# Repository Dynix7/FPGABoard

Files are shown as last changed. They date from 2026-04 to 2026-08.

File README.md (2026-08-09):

# FPGABoard
This is a FPGA (Field Programmable Array) board that consists of a iCE40 FPGA, FT2232 Programmer, and IO options. It has 2 PMOD headers (12 pin and 6 pin) along with an programming header and 26 pin header for anything else you want to plug in. On the board it has 3 LEDs and 3 buttons, allowing you to interact with the board without plugging anything in

# Why I Made It
I have a decent amount of experience working with microcontrollers but never any with FPGAs. I also want to learn Verilog which allows you to design circuits using programming, so a FPGA board would be perfect for this use case allowing me to experiment with Verilog and designing circuits while also learning something new.

# Pictures

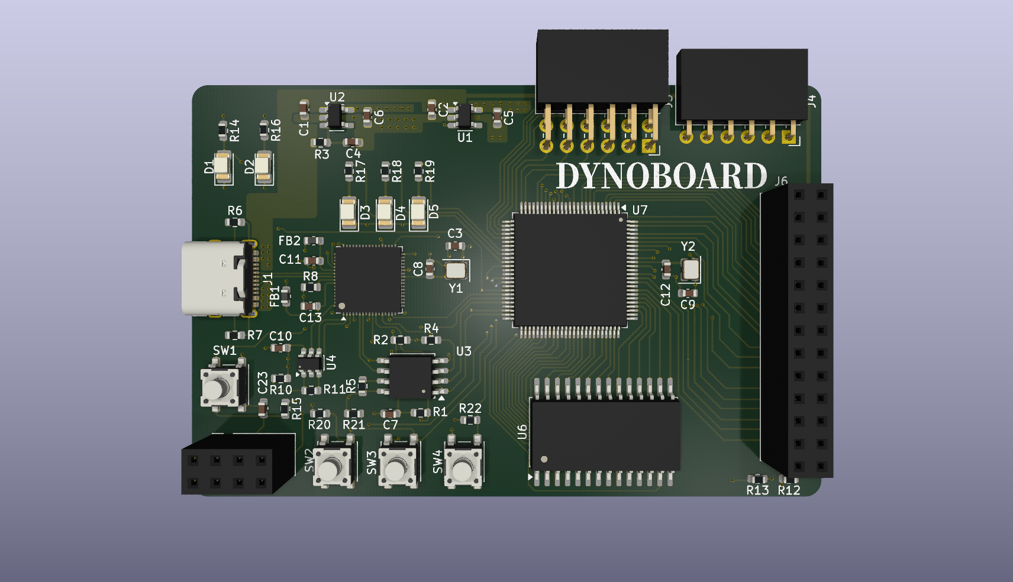
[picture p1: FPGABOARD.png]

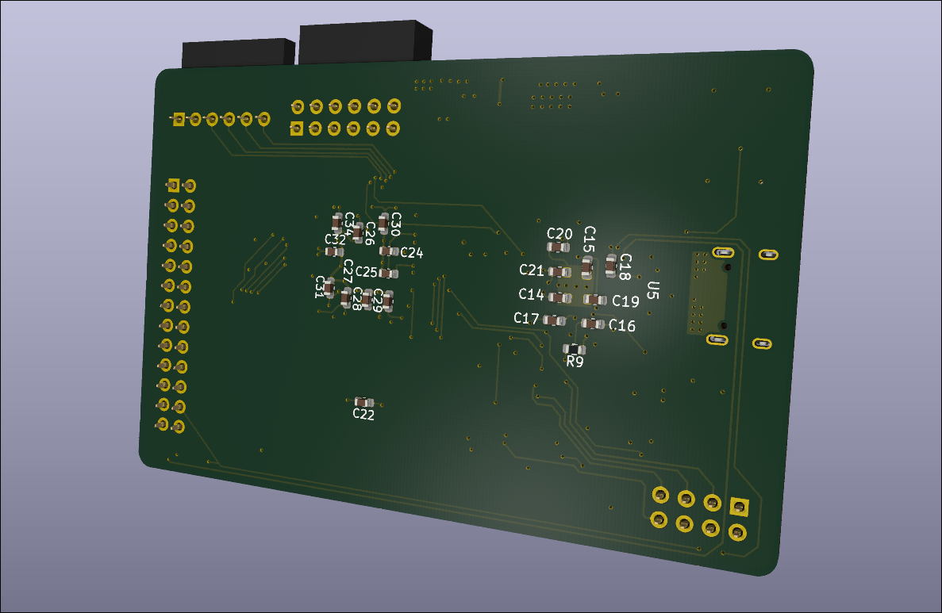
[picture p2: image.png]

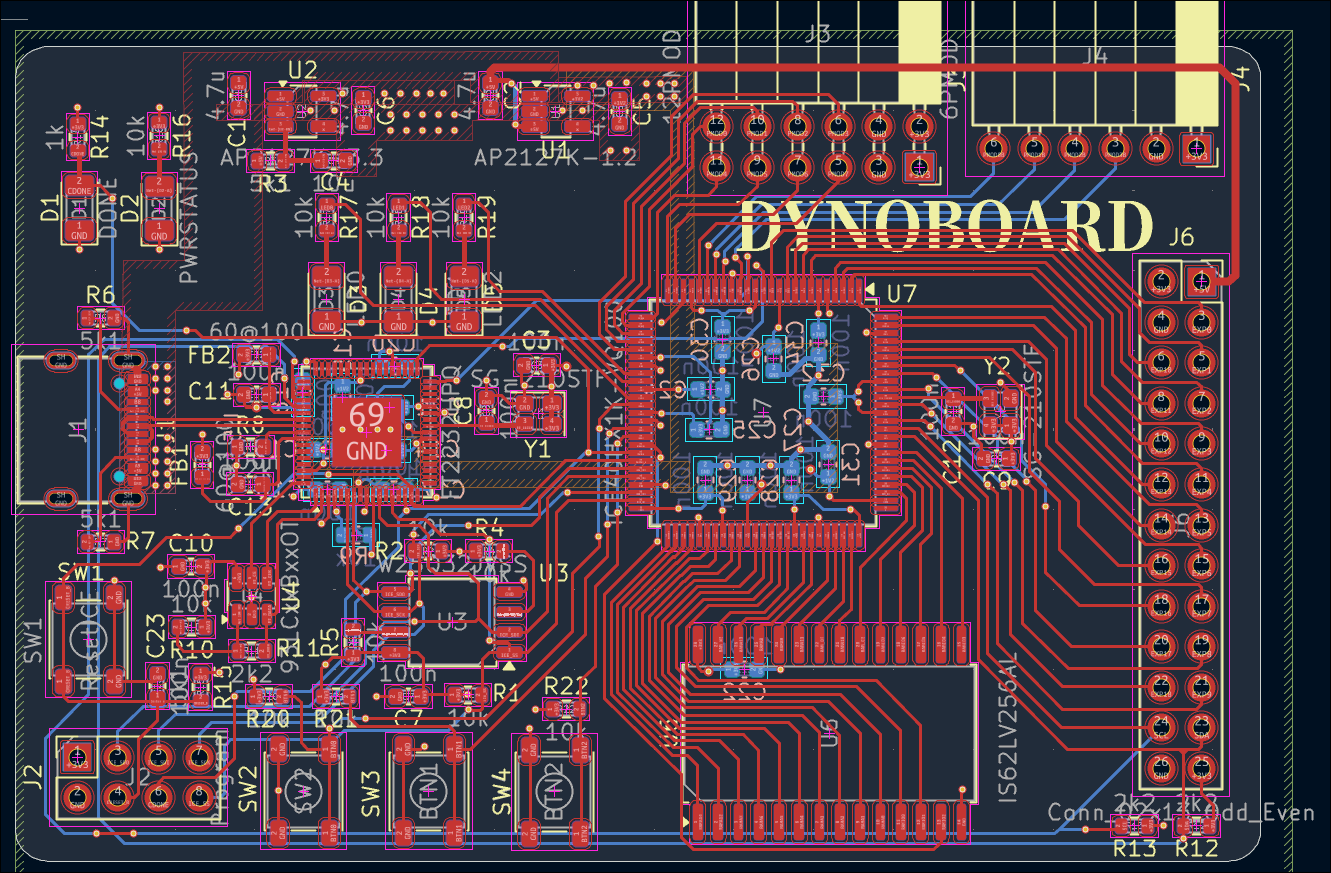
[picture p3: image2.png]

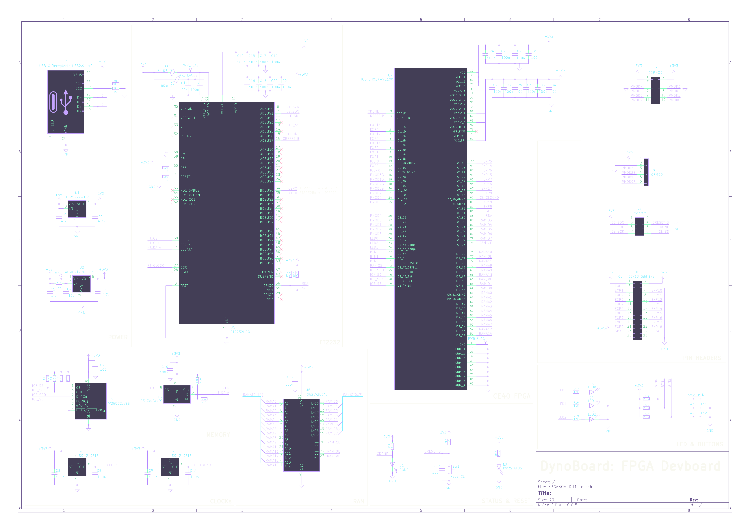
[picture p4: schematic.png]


# BOM

|Name |Purpose |Quantity|Total Cost (USD)|Link |Distributor|
|---|---|---|---|---|---|
|6 Pin Header |6 Pin PMOD Connector | |0.39 |https://www.lcsc.com/product-detail/C2935996.html |LCSC |
|2x6 Pin Header |12 Pin PMOD Connector | |0.74 |https://www.lcsc.com/product-detail/C47326634.html |LCSC |
|2x4 Pin Header |Programing Header | |0.52 |https://www.lcsc.com/product-detail/C7494793.html |LCSC |
|2x13 Pin Female Header|IO Pin Header | |0.32 |https://www.lcsc.com/product-detail/C19268725.html |LCSC |
|Ferrite Bead 60@100 |Power Filtering | |0.23 |https://www.lcsc.com/product-detail/C307775.html |LCSC |
|Solder Paste |Solder Components |1 |4.79 |https://www.aliexpress.us/item/3256809026940371.html |Aliexpress |
|4.7u Capacitors |Decoupling Capacitors | |0.10 | |LCSC |
|12k Resistor |Resistor | |0.11 | |LCSC |
|2.2k Resistor |Resistor | |0.13 | |LCSC |
|IS62LV256AL-45ULI |SRAM for Chip |1 |1.84 |https://www.digikey.com/short/70fz9v3d |Digikey |
|12Mhz Oscillator |Clock for FPGA and FT2232 |2 |0.87 |https://www.lcsc.com/product-detail/C37635404.html |LCSC |
|93LC66BT-I/OT |FT2232 Memory | |0.35 |https://www.digikey.com/short/q0nprmz5 |Digikey |
|AP2127K-1.2 |1.2V Voltage Regulator | |0.59 |https://www.lcsc.com/product-detail/C151376.html |LCSC |
|AP2127K-3.3 |3.3V Voltage Regulator | |0.53 |https://www.lcsc.com/product-detail/C156285.html |LCSC |
|FT2232HPQ |USB to SPI Chip for programming|1 |8.88 |https://www.lcsc.com/product-detail/C3228692.html |LCSC |
|iCE40HX1K-VQ100 |Main FPGA Chip |1 |12.17 |https://www.lcsc.com/product-detail/C1519043.html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|LCSC |
|Stencil |For PCB assembly |1 |7.11 | |JLCPCB |
|PCB |PCB for Build |5 |12.00 | |JLCPCB |

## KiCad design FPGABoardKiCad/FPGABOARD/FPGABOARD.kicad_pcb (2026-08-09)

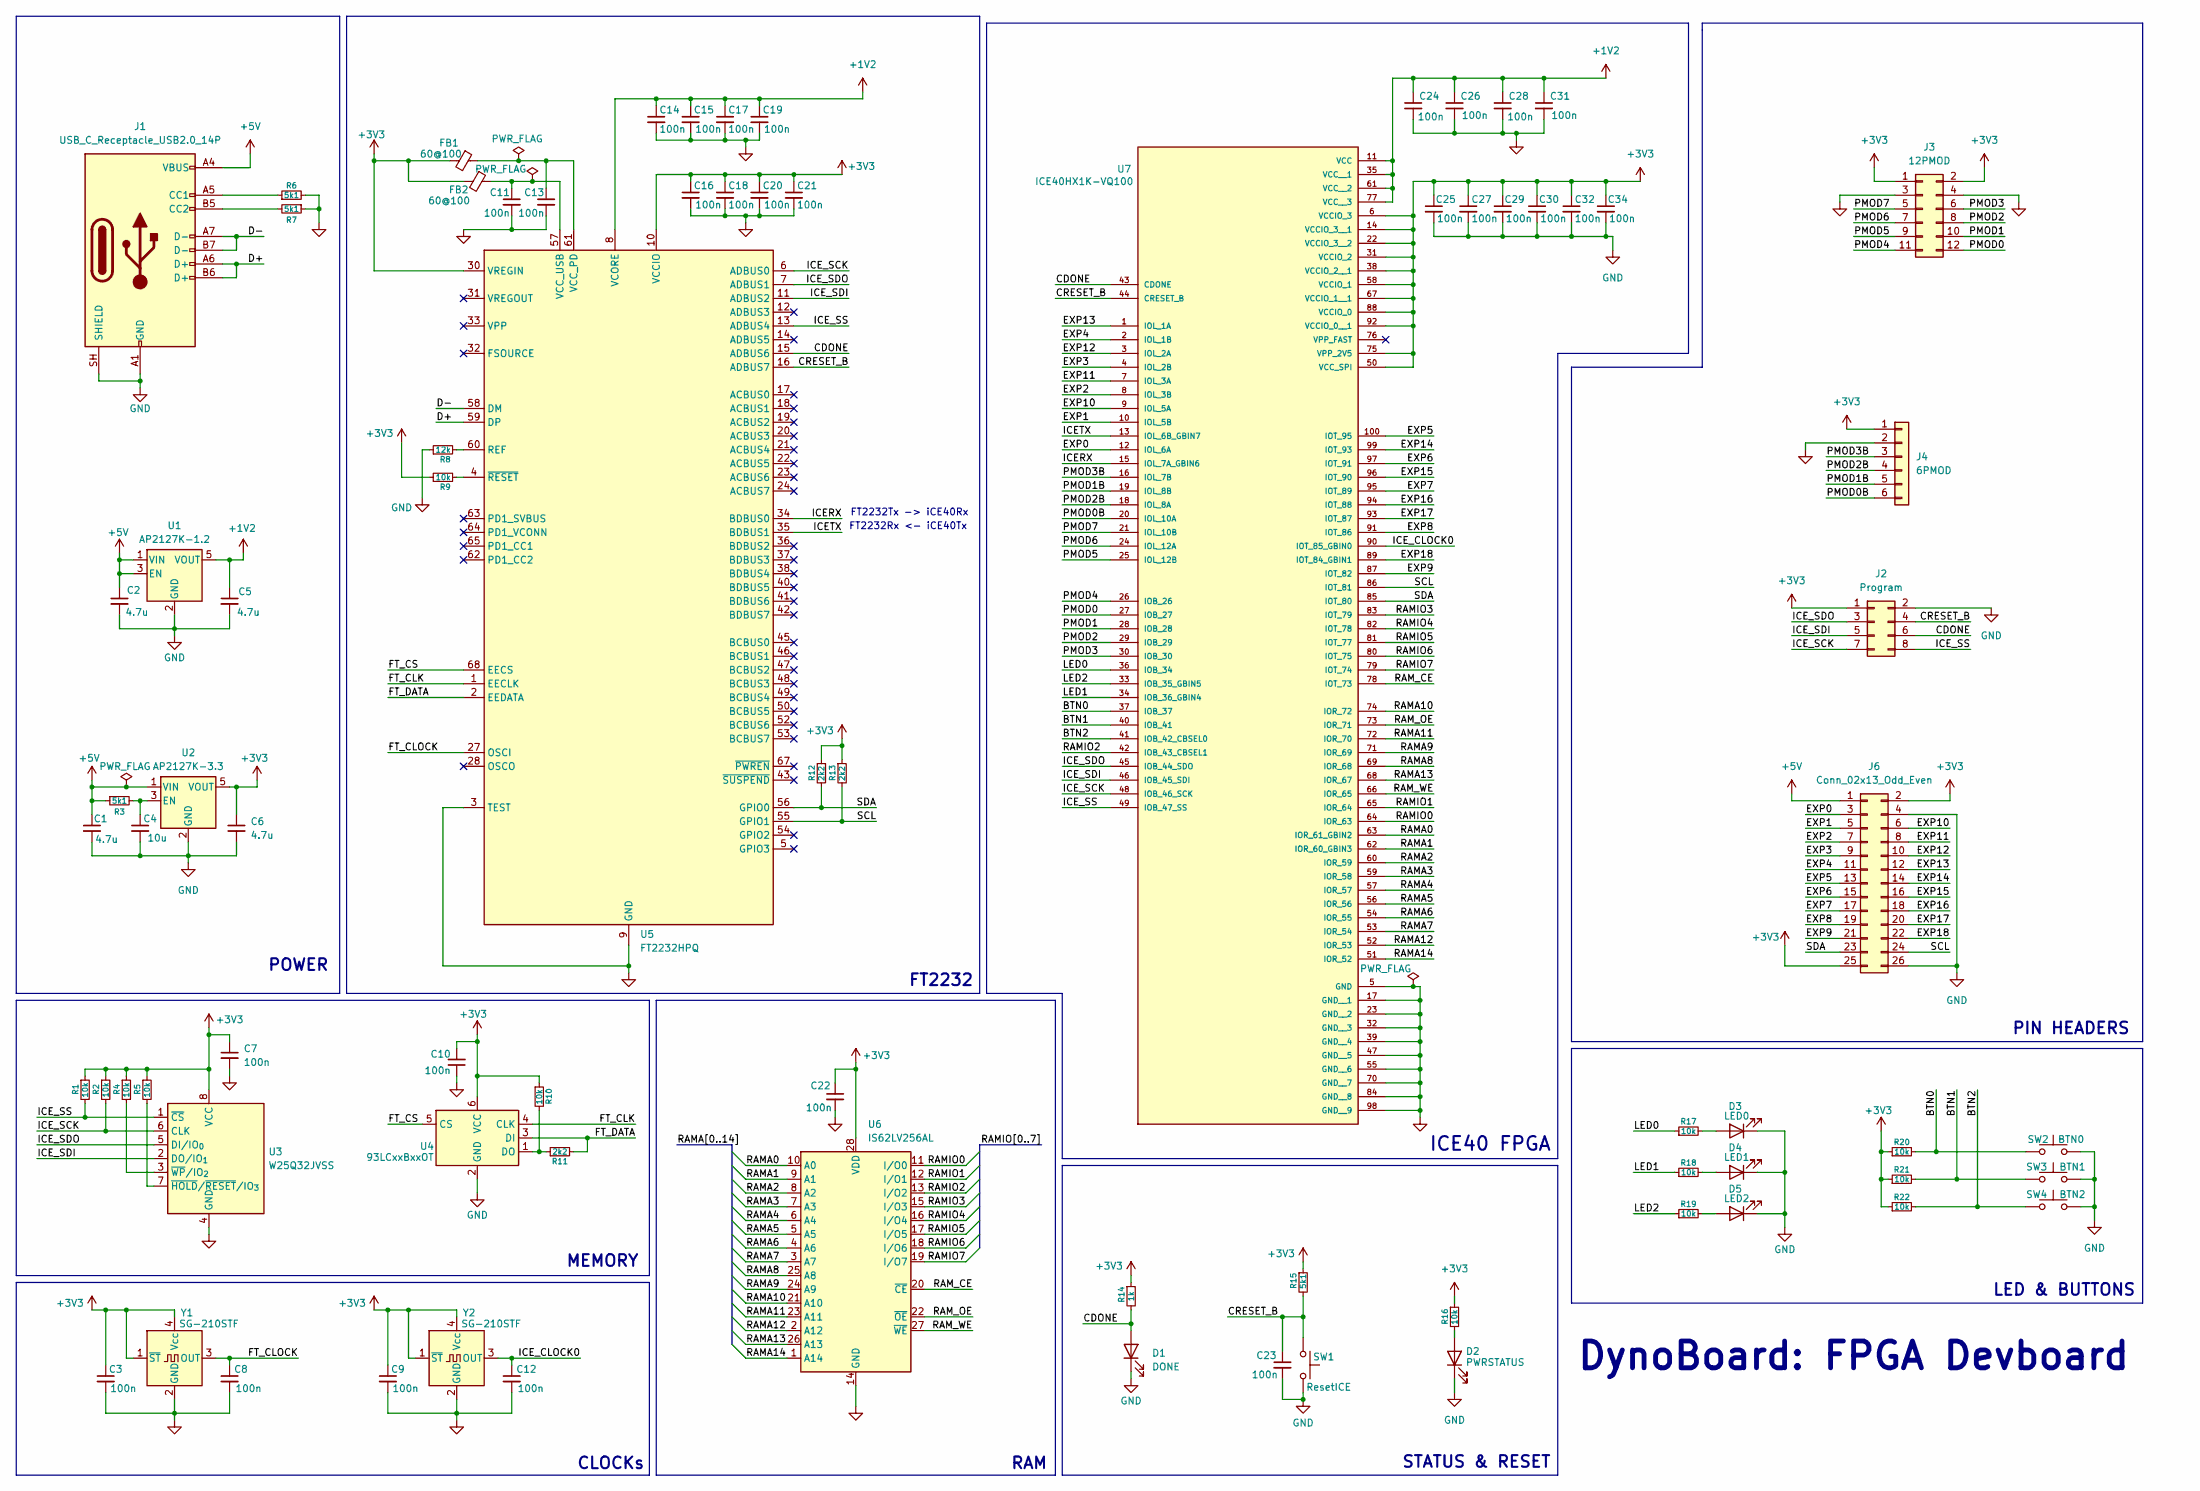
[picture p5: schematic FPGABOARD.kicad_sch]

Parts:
C1, C2, C5, C6: 4.7u; C_0603_1608Metric
C3, C7, C8, C9, C10, C11, C12, C13, C23: 100n; C_0603_1608Metric
C4: 10u; C_0603_1608Metric
C14, C15, C16, C17, C18, C19, C20, C21, C22, C24, C25, C26, C27, C28, C29, C30, C31, C32, C34: 100n; C_0603_1608Metric_Pad1.08x0.95mm_HandSolder
D1: DONE; LED_1206_3216Metric
D2: PWRSTATUS; LED_1206_3216Metric
D3: LED0; LED_1206_3216Metric
D4: LED1; LED_1206_3216Metric
D5: LED2; LED_1206_3216Metric
FB1, FB2: 60@100; L_0603_1608Metric
J1: USB_C_Receptacle_USB2.0_14P; USB_C_Receptacle_G-Switch_GT-USB-7010ASV
J2: Program; PinSocket_2x04_P2.54mm_Vertical
J3: 12PMOD; PinSocket_2x06_P2.54mm_Horizontal
J4: 6PMOD; PinSocket_1x06_P2.54mm_Horizontal
J6: Conn_02x13_Odd_Even; PinSocket_2x13_P2.54mm_Vertical
R1, R2, R4, R5, R10, R16, R17, R18, R19, R20, R21, R22: 10k; R_0603_1608Metric
R3, R6, R7, R15: 5k1; R_0603_1608Metric
R8: 12k; R_0603_1608Metric
R9: 10k; R_0603_1608Metric_Pad0.98x0.95mm_HandSolder
R11, R12, R13: 2k2; R_0603_1608Metric
R14: 1k; R_0603_1608Metric
SW1: ResetICE; SW_SPST_PTS647_Sx50
SW2: BTN0; SW_SPST_PTS647_Sx50
SW3: BTN1; SW_SPST_PTS647_Sx50
SW4: BTN2; SW_SPST_PTS647_Sx50
U1: AP2127K-1.2; SOT-23-5_HandSoldering
U2: AP2127K-3.3; SOT-23-5_HandSoldering
U3: W25Q32JVSS; SOIC-8_5.3x5.3mm_P1.27mm
U4: 93LCxxBxxOT; SOT-23-6
U5: FT2232HPQ; VQFN-68-1EP_8x8mm_P0.4mm_EP4.3x4.3mm
U6: IS62LV256AL; SOP-28_8.4x18.16mm_P1.27mm
U7: ICE40HX1K-VQ100; TQFP-100_14x14mm_P0.5mm; PARTREV 3.4
Y1, Y2: SG-210STF; Oscillator_SMD_SeikoEpson_SG210-4Pin_2.5x2.0mm

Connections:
+1V2: C5.1, C14.1, C15.1, C17.1, C19.1, C24.1, C26.1, C28.1, C31.1, U1.5 (VOUT), U5.8 (VCORE), U5.25 (VCORE), U5.44 (VCORE), U5.66 (VCORE), U7.11 (VCC), U7.35 (VCC__1), U7.61 (VCC__2), U7.77 (VCC__3)
+3V3: C3.1, C6.1, C7.1, C9.1, C10.2, C16.1, C18.1, C20.1, C21.1, C22.1, C25.1, C27.1, C29.1, C30.1, C32.1, C34.1, FB1.2, FB2.2, J2.1, J3.1, J3.2, J4.1, J6.2, J6.25, R1.1, R2.1, R4.1, R5.1, R9.1, R10.1, R12.1, R13.1, R14.1, R15.1, R16.1, R20.1, R21.1, R22.1, U2.5 (VOUT), U3.8 (VCC), U4.6 (VCC), U5.10 (VCCIO), U5.26 (VCCIO), U5.30 (VREGIN), U5.39 (VCCIO), U5.51 (VCCIO), U6.28 (VDD), U7.6 (VCCIO_3), U7.14 (VCCIO_3__1), U7.22 (VCCIO_3__2), U7.31 (VCCIO_2), U7.38 (VCCIO_2__1), U7.50 (VCC_SPI), U7.58 (VCCIO_1), U7.67 (VCCIO_1__1), U7.75 (VPP_2V5), U7.88 (VCCIO_0), U7.92 (VCCIO_0__1), Y1.1 (~ST), Y1.4 (Vcc), Y2.1 (~ST), Y2.4 (Vcc)
+5V: C1.1, C2.1, J1.A4 (VBUS), J1.A9 (VBUS), J1.B4 (VBUS), J1.B9 (VBUS), J6.1, R3.1, U1.1 (VIN), U1.3 (EN), U2.1 (VIN)
/BTN0: R20.2, SW2.1, U7.37 (IOB_37)
/BTN1: R21.2, SW3.1, U7.40 (IOB_41)
/BTN2: R22.2, SW4.1, U7.41 (IOB_42_CBSEL0)
/CDONE: D1.2 (A), J2.6, R14.2, U5.15 (ADBUS6), U7.43 (CDONE)
/CRESET_B: C23.1, J2.4, R15.2, SW1.1, U5.16 (ADBUS7), U7.44 (CRESET_B)
/D+: J1.A6 (D+), J1.B6 (D+), U5.59 (DP)
/D-: J1.A7 (D-), J1.B7 (D-), U5.58 (DM)
/EXP0: J6.3, U7.12 (IOL_6A)
/EXP1: J6.5, U7.10 (IOL_5B)
/EXP2: J6.7, U7.8 (IOL_3B)
/EXP3: J6.9, U7.4 (IOL_2B)
/EXP4: J6.11, U7.2 (IOL_1B)
/EXP5: J6.13, U7.100 (IOT_95)
/EXP6: J6.15, U7.97 (IOT_91)
/EXP7: J6.17, U7.95 (IOT_89)
/EXP8: J6.19, U7.91 (IOT_86)
/EXP9: J6.21, U7.87 (IOT_82)
/EXP10: J6.6, U7.9 (IOL_5A)
/EXP11: J6.8, U7.7 (IOL_3A)
/EXP12: J6.10, U7.3 (IOL_2A)
/EXP13: J6.12, U7.1 (IOL_1A)
/EXP14: J6.14, U7.99 (IOT_93)
/EXP15: J6.16, U7.96 (IOT_90)
/EXP16: J6.18, U7.94 (IOT_88)
/EXP17: J6.20, U7.93 (IOT_87)
/EXP18: J6.22, U7.89 (IOT_84_GBIN1)
/FT_CLK: U4.4 (CLK), U5.1 (EECLK)
/FT_CLOCK: C8.1, U5.27 (OSCI), Y1.3 (OUT)
/FT_CS: U4.5 (CS), U5.68 (EECS)
/FT_DATA: R11.2, U4.3 (DI), U5.2 (EEDATA)
/ICERX: U5.34 (BDBUS0), U7.15 (IOL_7A_GBIN6)
/ICETX: U5.35 (BDBUS1), U7.13 (IOL_6B_GBIN7)
/ICE_CLOCK0: C12.1, U7.90 (IOT_85_GBIN0), Y2.3 (OUT)
/ICE_SCK: J2.7, R2.2, U3.6 (CLK), U5.6 (ADBUS0), U7.48 (IOB_46_SCK)
/ICE_SDI: J2.5, U3.2 (DO/IO_{1}), U5.11 (ADBUS2), U7.46 (IOB_45_SDI)
/ICE_SDO: J2.3, U3.5 (DI/IO_{0}), U5.7 (ADBUS1), U7.45 (IOB_44_SDO)
/ICE_SS: J2.8, R1.2, U3.1 (~CS), U5.13 (ADBUS4), U7.49 (IOB_47_SS)
/LED0: R17.1, U7.36 (IOB_34)
/LED1: R18.1, U7.34 (IOB_36_GBIN4)
/LED2: R19.1, U7.33 (IOB_35_GBIN5)
/PMOD0: J3.12, U7.27 (IOB_27)
/PMOD0B: J4.6, U7.20 (IOL_10A)
/PMOD1: J3.10, U7.28 (IOB_28)
/PMOD1B: J4.5, U7.19 (IOL_8B)
/PMOD2: J3.8, U7.29 (IOB_29)
/PMOD2B: J4.4, U7.18 (IOL_8A)
/PMOD3: J3.6, U7.30 (IOB_30)
/PMOD3B: J4.3, U7.16 (IOL_7B)
/PMOD4: J3.11, U7.26 (IOB_26)
/PMOD5: J3.9, U7.25 (IOL_12B)
/PMOD6: J3.7, U7.24 (IOL_12A)
/PMOD7: J3.5, U7.21 (IOL_10B)
/RAMA0: U6.10 (A0), U7.63 (IOR_61_GBIN2)
/RAMA1: U6.9 (A1), U7.62 (IOR_60_GBIN3)
/RAMA2: U6.8 (A2), U7.60 (IOR_59)
/RAMA3: U6.7 (A3), U7.59 (IOR_58)
/RAMA4: U6.6 (A4), U7.57 (IOR_57)
/RAMA5: U6.5 (A5), U7.56 (IOR_56)
/RAMA6: U6.4 (A6), U7.54 (IOR_55)
/RAMA7: U6.3 (A7), U7.53 (IOR_54)
/RAMA8: U6.25 (A8), U7.69 (IOR_68)
/RAMA9: U6.24 (A9), U7.71 (IOR_69)
/RAMA10: U6.21 (A10), U7.74 (IOR_72)
/RAMA11: U6.23 (A11), U7.72 (IOR_70)
/RAMA12: U6.2 (A12), U7.52 (IOR_53)
/RAMA13: U6.26 (A13), U7.68 (IOR_67)
/RAMA14: U6.1 (A14), U7.51 (IOR_52)
/RAMIO0: U6.11 (I/O0), U7.64 (IOR_63)
/RAMIO1: U6.12 (I/O1), U7.65 (IOR_64)
/RAMIO2: U6.13 (I/O2), U7.42 (IOB_43_CBSEL1)
/RAMIO3: U6.15 (I/O3), U7.83 (IOT_79)
/RAMIO4: U6.16 (I/O4), U7.82 (IOT_78)
/RAMIO5: U6.17 (I/O5), U7.81 (IOT_77)
/RAMIO6: U6.18 (I/O6), U7.80 (IOT_75)
/RAMIO7: U6.19 (I/O7), U7.79 (IOT_74)
/RAM_CE: U6.20 (~CE), U7.78 (IOT_73)
/RAM_OE: U6.22 (~OE), U7.73 (IOR_71)
/RAM_WE: U6.27 (~WE), U7.66 (IOR_65)
/SCL: J6.24, R13.2, U5.55 (GPIO1), U7.86 (IOT_81)
/SDA: J6.23, R12.2, U5.56 (GPIO0), U7.85 (IOT_80)
GND: C1.2, C2.2, C3.2, C4.2, C5.2, C6.2, C7.2, C8.2, C9.2, C10.1, C11.2, C12.2, C13.2, C14.2, C15.2, C16.2, C17.2, C18.2, C19.2, C20.2, C21.2, C22.2, C23.2, C24.2, C25.2, C26.2, C27.2, C28.2, C29.2, C30.2, C31.2, C32.2, C34.2, D1.1 (K), D2.1 (K), D3.1 (K), D4.1 (K), D5.1 (K), J1.A1 (GND), J1.A12 (GND), J1.B1 (GND), J1.B12 (GND), J1.SH (SHIELD), J2.2, J3.3, J3.4, J4.2, J6.4, J6.26, R6.2, R7.1, R8.1, SW1.2, SW2.2, SW3.2, SW4.2, U1.2 (GND), U2.2 (GND), U3.4 (GND), U4.2 (GND), U5.3 (TEST), U5.9 (GND), U5.29 (GND), U5.69 (GND), U6.14 (GND), U7.5 (GND), U7.17 (GND__1), U7.23 (GND__2), U7.32 (GND__3), U7.39 (GND__4), U7.47 (GND__5), U7.55 (GND__6), U7.70 (GND__7), U7.84 (GND__8), U7.98 (GND__9), Y1.2 (GND), Y2.2 (GND)
unnamed: D2.2 (A), R16.2
unnamed: D3.2 (A), R17.2
unnamed: D4.2 (A), R18.2
unnamed: D5.2 (A), R19.2
unnamed: J1.A5 (CC1), R6.1
unnamed: J1.B5 (CC2), R7.2
unnamed: C4.1, R3.2, U2.3 (EN)
unnamed: R5.2, U3.7 (~HOLD/~RESET/IO_{3})
unnamed: R4.2, U3.3 (~WP/IO_{2})
unnamed: R10.2, R11.1, U4.1 (DO)
unnamed: R8.2, U5.60 (REF)
unnamed: C13.1, FB1.1, U5.61 (VCC_PD)
unnamed: C11.1, FB2.1, U5.57 (VCC_USB)
unnamed: R9.2, U5.4 (~RESET)

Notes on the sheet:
RAM
FT2232Rx <- iCE40Tx
FT2232Tx -> iCE40Rx
PIN HEADERS
LED & BUTTONS
FT2232
DynoBoard: FPGA Devboard
CLOCKs
ICE40 FPGA
STATUS & RESET
MEMORY
POWER

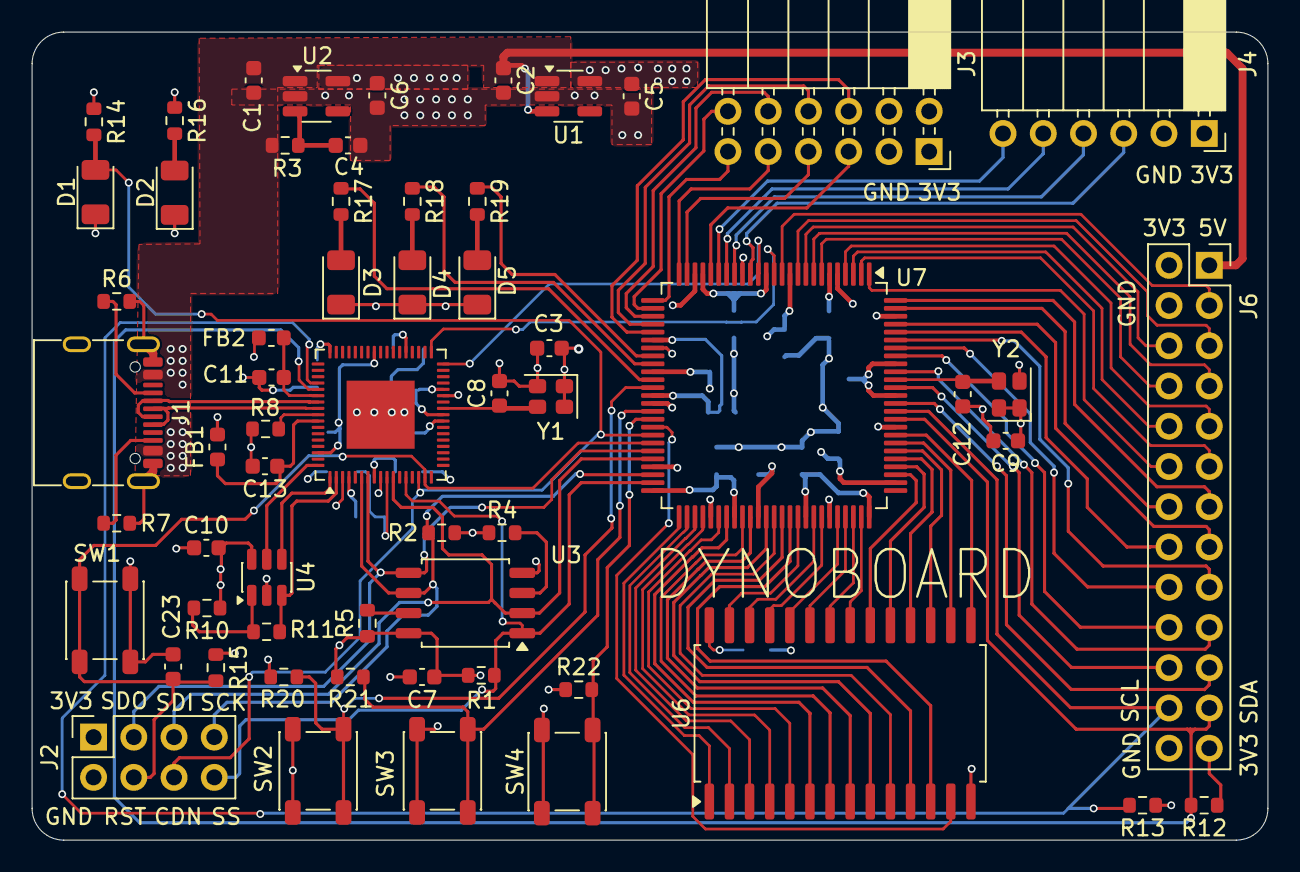
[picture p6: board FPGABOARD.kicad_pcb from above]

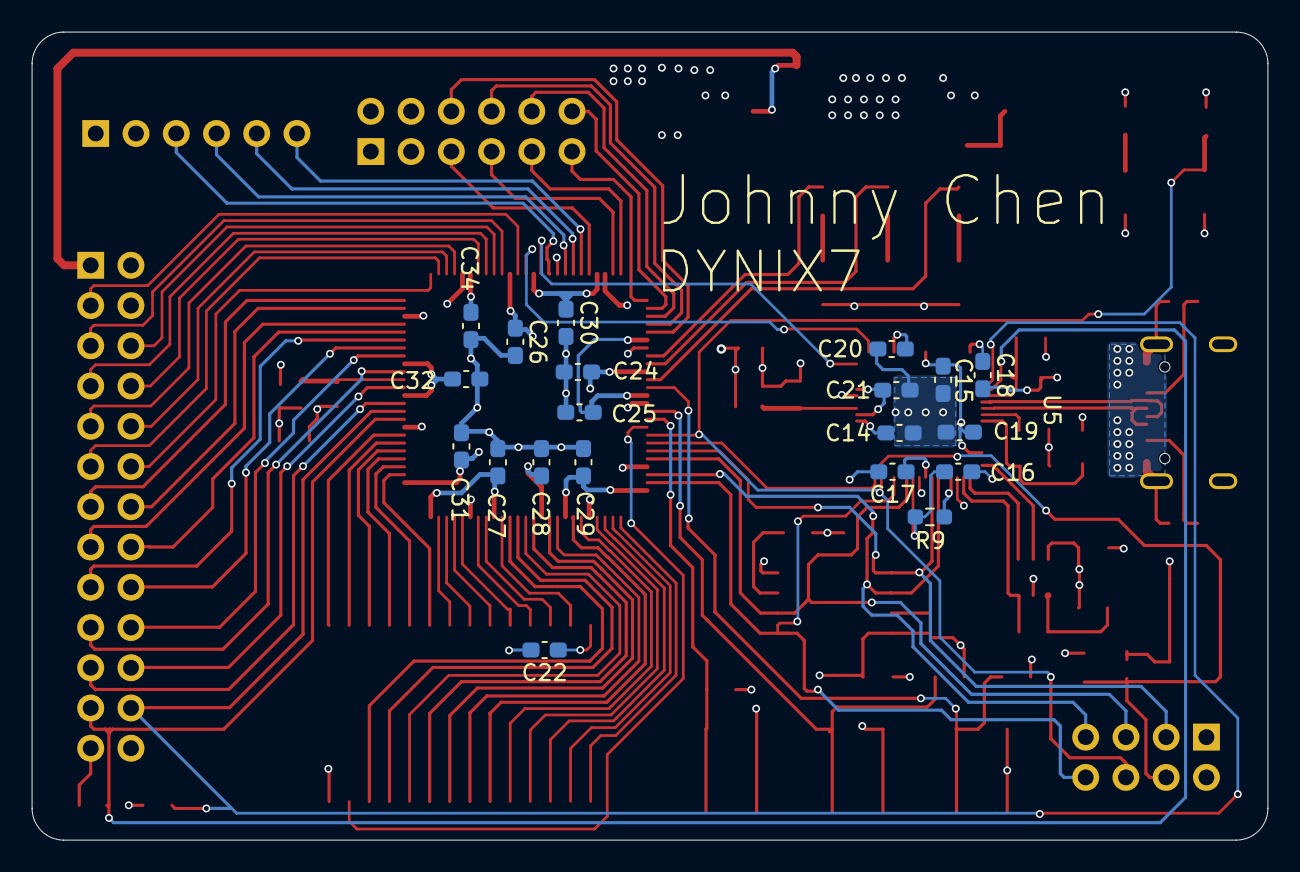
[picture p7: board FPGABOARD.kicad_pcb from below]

Board: 4 copper layers, 78.0 x 51.0 mm, 80 parts (20 on the bottom side), 98 nets.

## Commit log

2026-04-08 Start Schematic
    [FPGABOARD.kicad_pcb, FPGABOARD.kicad_sch]
2026-04-09 Schematic Work
    [FPGABOARD.kicad_sch]
2026-04-10 FT2232 Wiring
    [FPGABOARD.kicad_pcb, FPGABOARD.kicad_sch]
2026-04-10 Update IO
    [FPGABOARD.kicad_pcb, FPGABOARD.kicad_sch]
2026-04-13 Some placements
    [FPGABOARD.kicad_pcb, FPGABOARD.kicad_sch]
2026-04-15 More pcb work
    [FPGABOARD.kicad_pcb]
2026-04-16 More placements
    [FPGABOARD.kicad_pcb]
2026-04-17 Finished placements mostly
    [FPGABOARD.kicad_pcb, FPGABOARD.kicad_sch]
2026-04-19 Finsished up Header and Memory routing
    [FPGABOARD.kicad_pcb, FPGABOARD.kicad_sch]
2026-04-19 Minor wiring change
    [FPGABOARD.kicad_pcb]
2026-04-19 Add programing header
    [FPGABOARD.kicad_pcb, FPGABOARD.kicad_sch]
2026-04-19 Changed to 0603
    [FPGABOARD.kicad_pcb, FPGABOARD.kicad_sch]
2026-04-20 image update
    [FPGABOARD.kicad_pcb]
2026-04-23 add bom
    [FPGABOARD.kicad_pcb]
2026-08-09 schematic image
    [FPGABOARD.kicad_pcb, FPGABOARD.kicad_sch]
